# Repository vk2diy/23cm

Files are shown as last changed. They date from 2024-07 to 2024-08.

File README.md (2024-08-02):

# 23cm NBFM transceiver

An open source 23cm narrow band FM transceiver.

[KiCad](https://www.kicad.org/) format, optimized for building with [LCSC](https://www.lcsc.com/) and [JLCPCB](https://www.jlcpcb.com/).

Status: Schematic under active redefinition, BOM largely verified, firmware converted to platformio and compiling, some required symbols drawn, schematic as yet incomplete and revised layout not yet begun. Translated original article. Some mechanical design work and supply chain research completed. Getting bogged down in theory but learning a lot. Modeled some subsystems.

## Background

Prompted by a presentation by Richard (VK2VD) at Amateur Radio NSW on the 28th of July, 2024, this repository attempts to provide a design including all KiCad source files representing a derivative of the design by Bas de Jong (PE1JPD) with later firmware updates by Werner Mauser (JN48OL).

Various changes have been made to the design, outlined below.

## Original design details

Bas de Jong (PE1JPD)'s [original project page](http://www.pe1jpd.nl/index.php/23cm_nbfm/) describes the overall design, made in 2015, notably including this 2016 revised schematic.

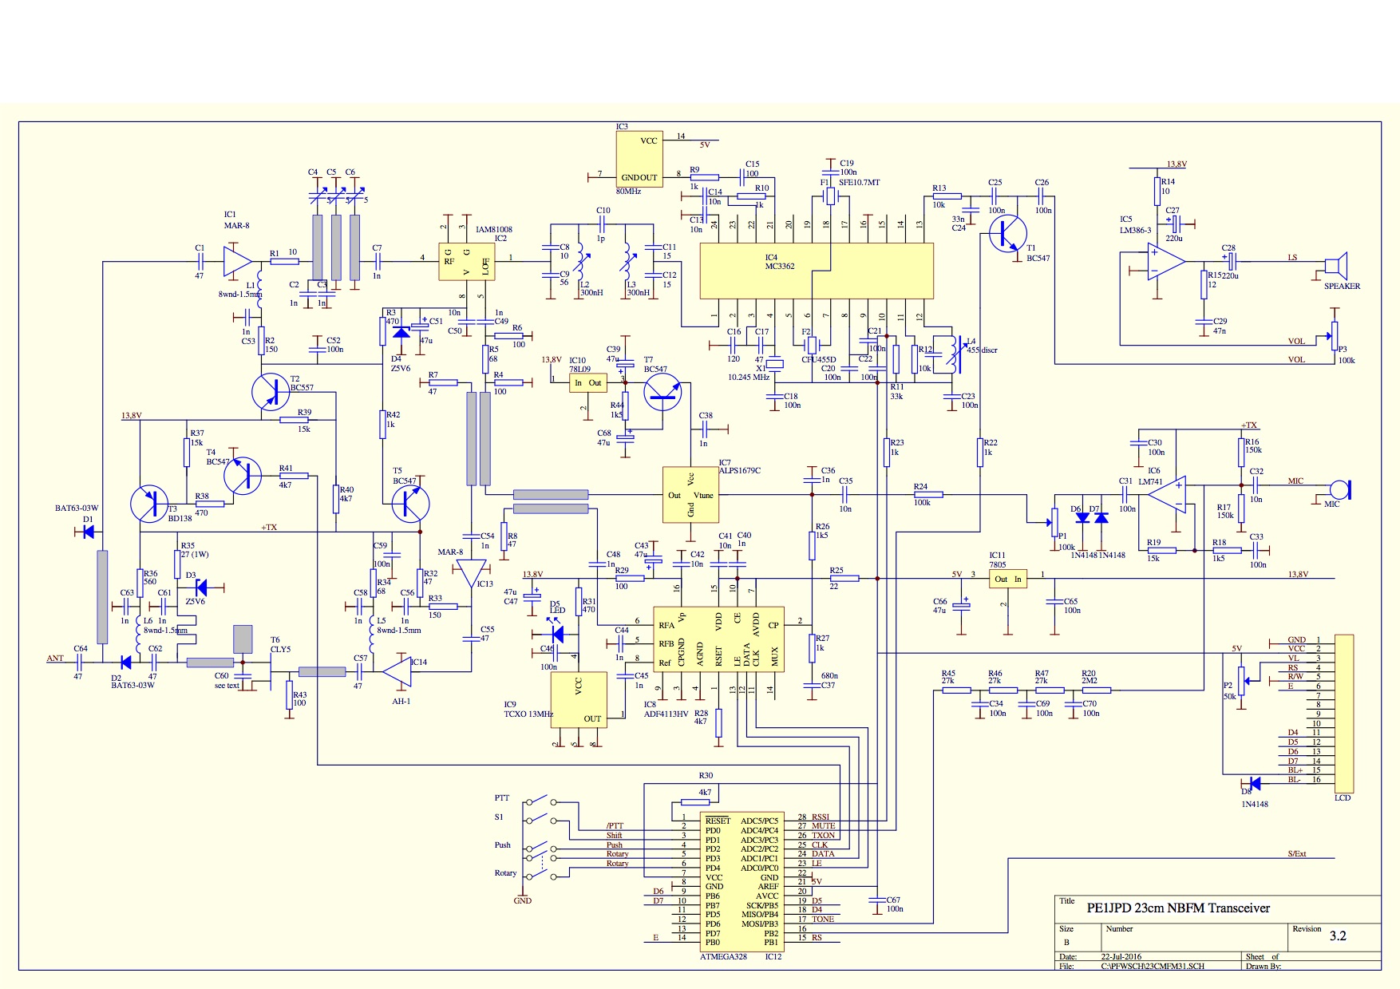
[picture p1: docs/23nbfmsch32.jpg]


Werner Mauser (JN48OL)'s [forked repository](https://github.com/wemaus/23cm-NBFM-Trx) provides firmware improvements, notably including a further revised schematic redrawn in KiCad 3.0.

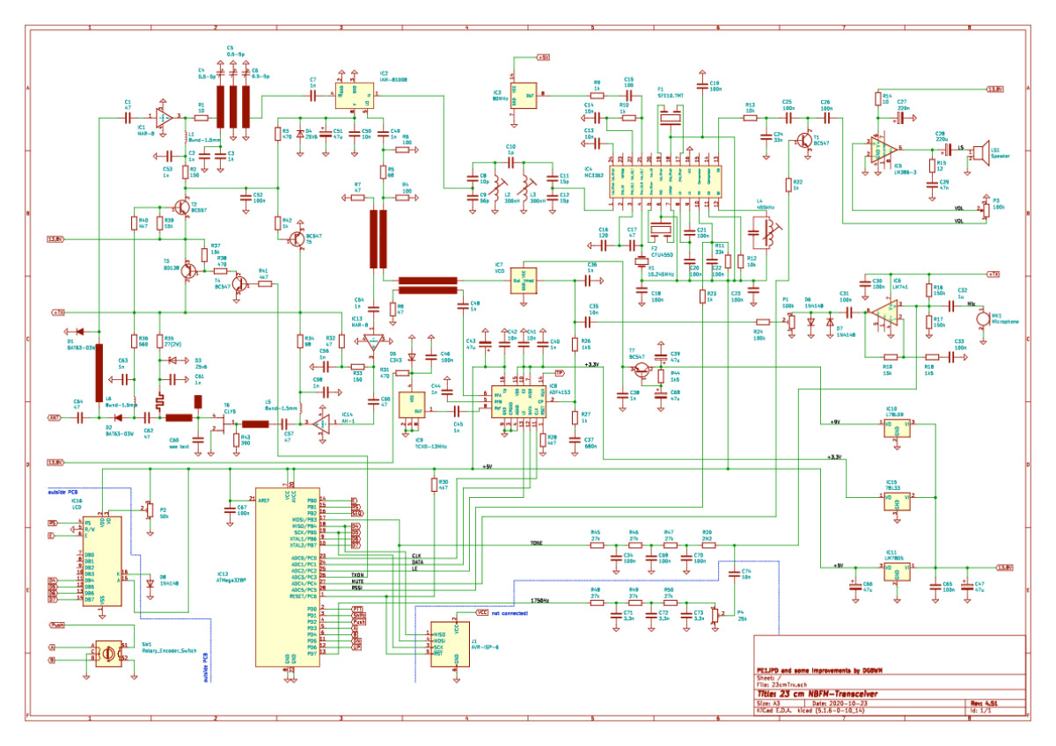
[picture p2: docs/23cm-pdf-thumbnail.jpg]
 

## Changes from prior versions

 * __Amplifier__: Maintained 2 x MAR-8 series amplifiers per original design, noting alternatives generally present worse noise performance, lower gain, and are footprint incompatible.
 * __Buses__: The "SPI compatible" bus on the ADF4153 was moved to the standard ports. The I2C bus was added to support the new display module and other expansion.
 * __Components__: Near complete reselection with a focus on SMT components available in 2024. General preference to over-specify components where economically insignificant to increase tolerance and longevity.
 * __Display__: Migrate the LCD to an I2C interface. Nominally opens up I2C for other peripherals and features. Much neater in terms of simplifying the schematic. Allows more flexibility in mechanical design/interface mounting. Necessitates re-allocating `MUTE` and `RSSI` to alternate pins, plus software changes. Necessitates off-board module and cable. Programmable backlight with MCU control, and one less knob. User retains option for manual adjustment using module-supplied jumper and internal potentiometer.
 * __Interface__: Try to migrate potentiometers to MCU-control where feasible, eg. CTCSS/1750MHz tuner, LCD backlight control.
 * __Filters__: [Explicitly modeling](docs/filter-models/) each filter network encountered. Apparently modern ceramic filters have superior properties in terms of bandwidth and attenuation compared to the dark depths of the 1990s from which the previous designs components were sourced.
 * __Firmware__: Now compiles with [platformio](https://piolabs.com/).
 * __MCU__: Use an MCU module (Arduino Nano v3) instead of a bare chip in order to reduce cost, increase convenience, support USB programming, and focus the schematic on the application.
 * __Oscillators__: Investigating the option/benefit/limitations of upgrading the reference temperature controlled crystal oscillator (TCXO) to a higher frequency and/or gold-plated version. Frequencies available include 14.4MHz, 20MHz, 28.8MHz, 30MHz, 50MHz, 100MHz, 200MHz. Nominally this will bring benefits in selectivity but also challenges. Availability seems a non-issue, cost differences are nominal.
 * __Power supply__: Drop 13.8V DC 'charged lead acid battery level' input to support a modern supply voltage (24V) and include a regulator with high current support.
 * __Schematic__: Completely redrawn to emphasize legibility through reducing cognitive load with block-based / modular schematic. Use named labels instead of single page all-in-one view with crossed nets. Hopefully still works!
 * __VCO__: Neither of the VCOs mentioned seem to be obtainable. A shortlist of potential replacements has been gathered. No doubt voltage levels on both the supply and tuning sides will need adjustment in order to integrate.
   * M1200 (+0-5V = 1150-1350MHz) - 6RMB @ [Manufacturer](https://www.fresend.com/productinfo/647892.html)
   * RFINT INNOTION YSGM 111308 (+0.5-4.5V = 1100-1350MHz, nominal 1050-1400MHz support) - $1.14 @ [AliExpress](https://www.aliexpress.com/item/1005005589982171.html)
   * FDK IR013 (1200-1400MHz) - $1.08 @ [AliExpress](https://www.aliexpress.com/item/1005007461973192.html)
   * UCVE1-W05A (marked "A041"; 1200-1670MHz) - $0.89 @ [AliExpress](https://www.aliexpress.com/item/1005005589963281.html)
   * MURATA MQW540A1G40R6 (1200-1600MHz) - $1.73 @ [AliExpress](https://www.aliexpress.com/item/1005007376224853.html)
   * MARUWA MVE-1377 (marked "E1377"; 1200-1400MHz) - $1.73 @ [AliExpress](https://www.aliexpress.com/item/1005007372058424.html)
   * ENFVH1D2SA4 (marked "12 VHA4"; 1200-1400MHz) - $2.16 @ [AliExpress](https://www.aliexpress.com/item/1005007376529487.html)

## Contents

 * __docs__: Design documentation. Some interesting stuff in here.
 * __firmware__: Currently unaltered firmware from Werner Mauser (JN48OL) converted to compile with platformio.
 * __23cm-trx-kicad__: KiCad project directory for the 23cm transceiver.

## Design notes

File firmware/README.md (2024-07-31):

# Firmware for 23cm NBFM transceiver

Currently unaltered firmware from [Werner Mause (JN48OL)](https://github.com/wemaus/23cm-NBFM-Trx).

The directory structure has been altered to match [platformio](https://piolabs.com/) standards.

The code is due to be modified to accomodate revised schematic.

In the mean time, the following works.

## Build the code

 * Normal build: `pio run`
 * Verbose build: `pio run -v`

## Lint the code

 * `pio check`

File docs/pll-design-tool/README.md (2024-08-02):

# PLL Design Tool

The tool recommended by the manufacture of the PLL synthesis chip is [ADIsimPLL](https://www.analog.com/en/lp/resources/adisimpll.html).

The version currently available for download was built on April 18, 2024.

## Download and install

The tool is designed for Windows but can be downloaded under Linux and run under [wine](https://www.winehq.org/).

The direct download script is as follows:

```
wget https://www.analog.com/media/en/engineering-tools/design-tools/adisimpll_v5_80_01_setup.zip && \
unzip adisimpll_v5_80_01_setup.zip && \
cd adisimpll_v5_80_01_setup && \
wine64-vanilla-9.0 ADIsimPLL_V5_80_01_setup.exe
```

Note that your `wine` instllation may required a slightly different binary name when executing the final command.

On any modern Linux, press `wine<tab><tab>` to see a list of contenders.

## Running the tool

Under Linux you can run the following command to start ADIsimPLL after installation.

```
wine64-vanilla-9.0 'c:\program files (x86)\applied radio labs\adisimpll ver 5.80\bin\simpll_ad.exe'
```

### Making things easier

There may be a better way to do this but I'm not a regular wine user.

Given this command line is a hassle to type, if you want to run this more than once you can create an alias like this:
```
alias adisimpll="wine64-vanilla-9.0 'c:\program files (x86)\applied radio labs\adisimpll ver 5.80\bin\simpll_ad.exe'"
```

Store than in your `~/.bashrc` (or other shell initialization file) in order to make it permanent.

You will now be able to run the tool by typing `adisimpll`.

## Notes

The software includes general rule-of-thumb characterisations of different filter designs which are presumably well founded.

## Tips

There is an interesting `tips.txt` file included with the software. A lot of it is marketing or irrelevant but some of the more interesting portions include:

 * You can measure the tuning data for a VCO (presumably a table of known input voltages vs. observed output oscillation frequencies), then store it in the system to model.
 * The ADF4116, ADF4117 and ADF4118 are pin compatible,  lower phase noise replacements for the LMX2306, LMX2316 and LMX2326 single devices respectively.   Drop-in replacements for the LMX dual devices are also available. The ADF4116, ADF4117 and ADF4118 devices use fixed prescalers and can operate up to 3.0GHz.   The ADF4110 through ADF4113 single PLL devices (and ADF4210 through ADF4213 dual PLL devices) allow control of prescaler division ratio and can operate up to 4.0GHz.
 * There is a reference doubler on-chip in all the ADF4000 series Fractional-N models. This allows the input reference signal to be doubled. This is useful for increasing the PFD comparison frequency. Making the PFD frequency higher improves the overall PLL system noise performance. Doubling the PFD frequency will usually result in an improvement in noise performance of 3dB.
 * For certain designs sourcing high performance clock devices is desirable in order to reduce jitter.
 * ADF4110 through ADF4113 single PLL devices (and ADF4210 through ADF4213 dual PLL devices) allow control of prescaler division ratio over the range 8/9, 16/17, 32/33 and 64/65. Minimizing the prescaler division ratio allows the phase detector to run at higher frequencies without missing channels, reducing phase noise and accelerating switching times. However, be sure to ensure that the highest output frequency from the prescaler does not exceed the Maximum Allowable Prescaler Output Frequency specified on the datasheet: ADI SimPLL automatically checks this.

## Screenshots

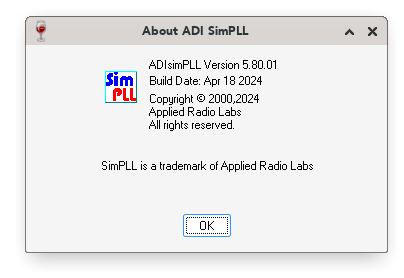
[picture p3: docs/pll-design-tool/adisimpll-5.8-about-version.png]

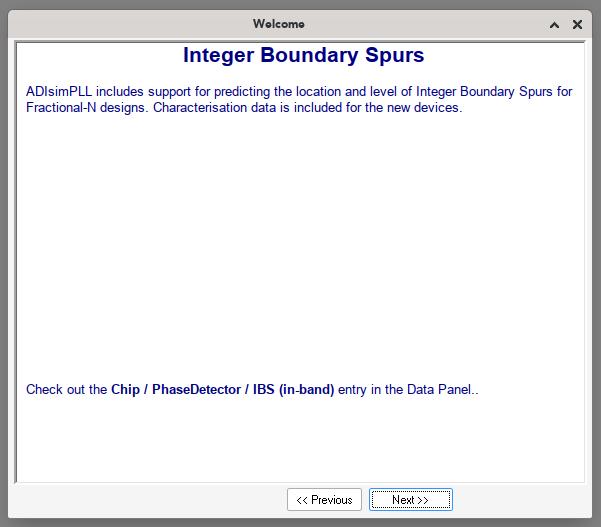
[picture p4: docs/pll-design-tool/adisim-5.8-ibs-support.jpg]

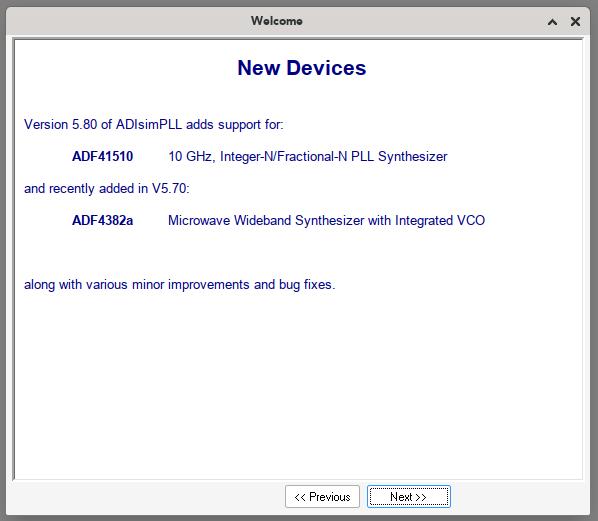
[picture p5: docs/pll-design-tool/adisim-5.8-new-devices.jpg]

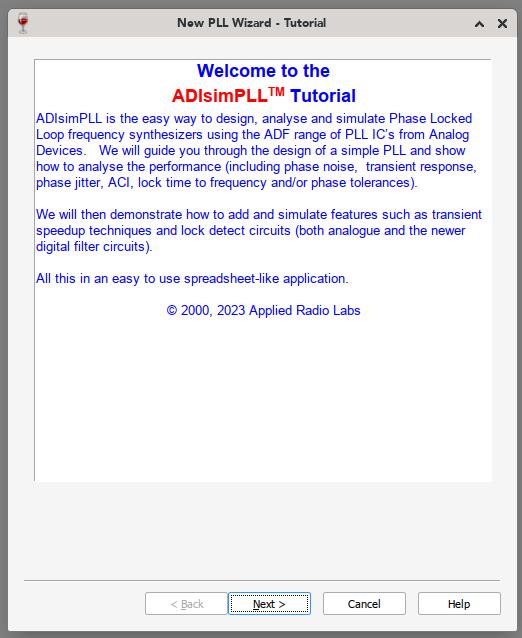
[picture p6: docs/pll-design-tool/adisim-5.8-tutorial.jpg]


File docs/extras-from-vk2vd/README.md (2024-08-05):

# Extra resources from VK2VD

VK2VD was kind enough to send me some further information.

First, he provided some English translations of stages 2 and 3 of [Wemaus' build site](http://www.mdtweb.de/index.php/projekte/nachrichtentechnik/nachrichtengeraete/23-cm-fm-transceiver/). I have not included those here in the repository because you can easily generate your own translations using [translate.google.com](https://translate.google.com) or similar services and being docx files with images they were relatively large.

Second, he provided a higher resolution version of his revised schematic which incorporates his suggested fixes to thermal issues observed with the previous schematic.

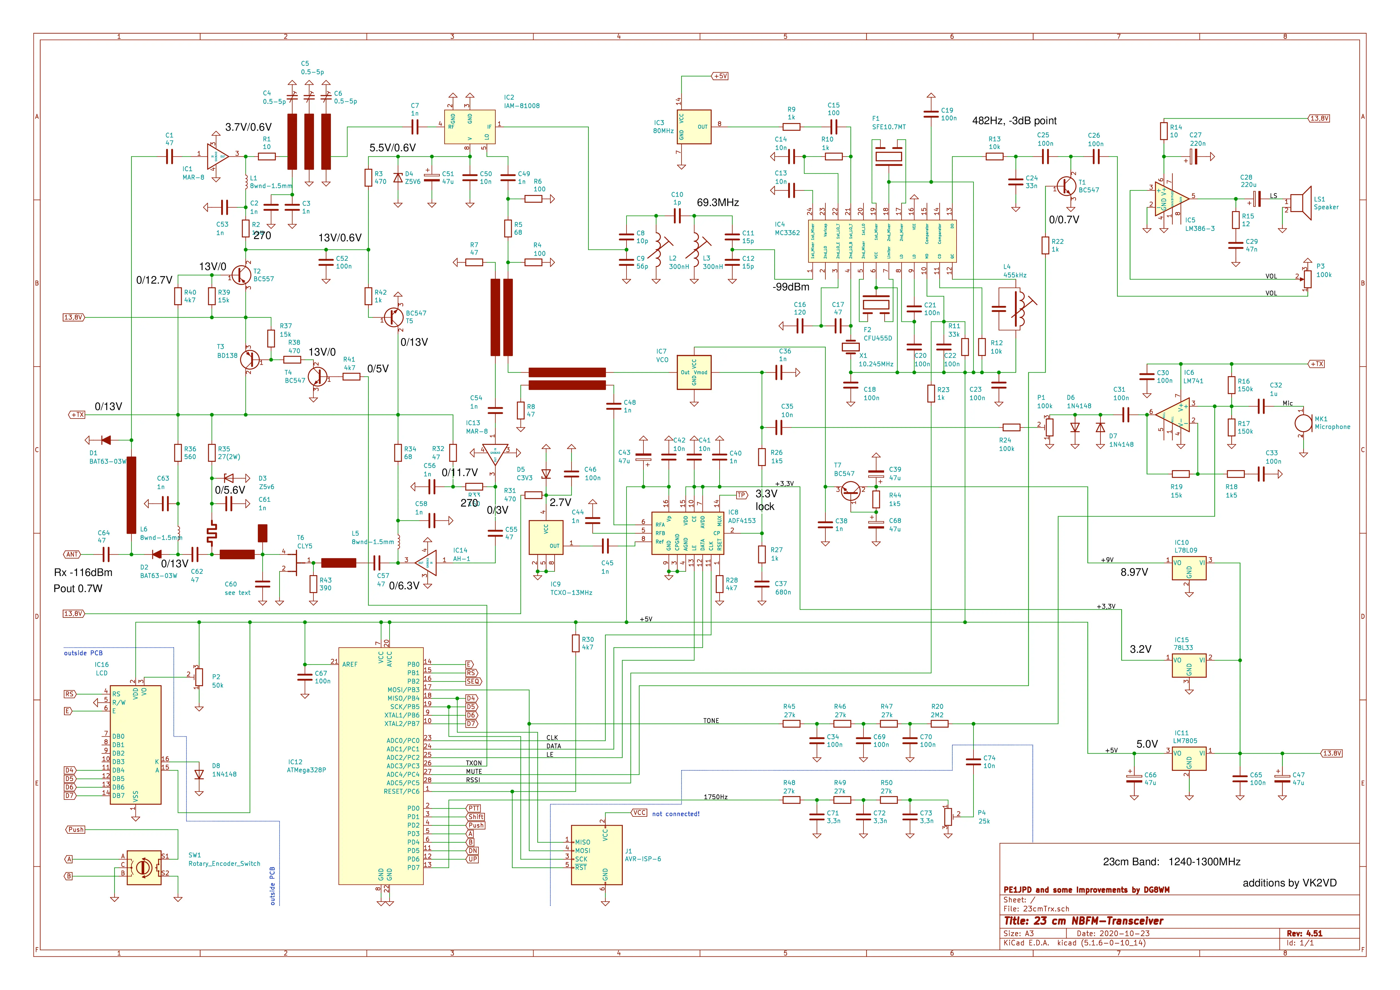
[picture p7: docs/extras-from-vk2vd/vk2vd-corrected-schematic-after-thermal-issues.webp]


Finally, he provided the following Sketch by DG8WM showing the PLL system.

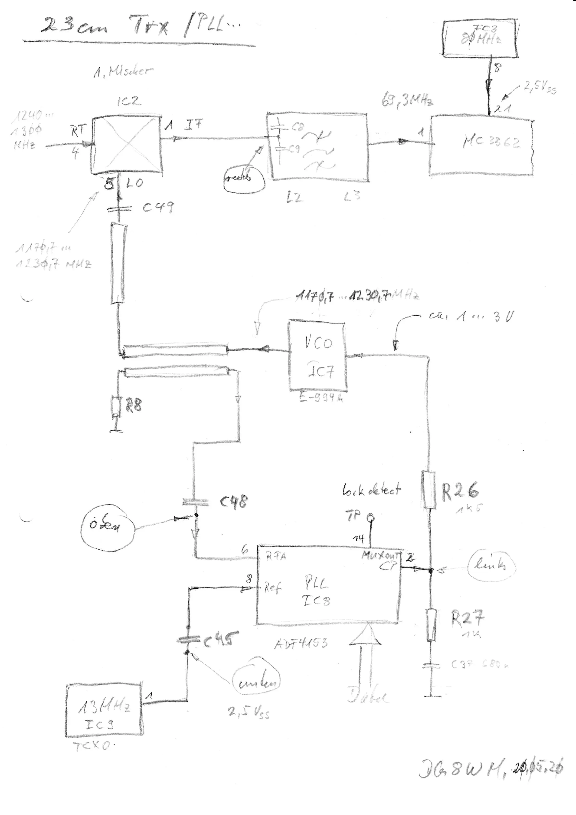
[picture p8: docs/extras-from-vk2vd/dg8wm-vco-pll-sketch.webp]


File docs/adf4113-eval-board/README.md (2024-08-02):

# ADF4113HV Eval Board

The evaluation board design is interesting. The PDF has further detail, but here is the base screenshot.

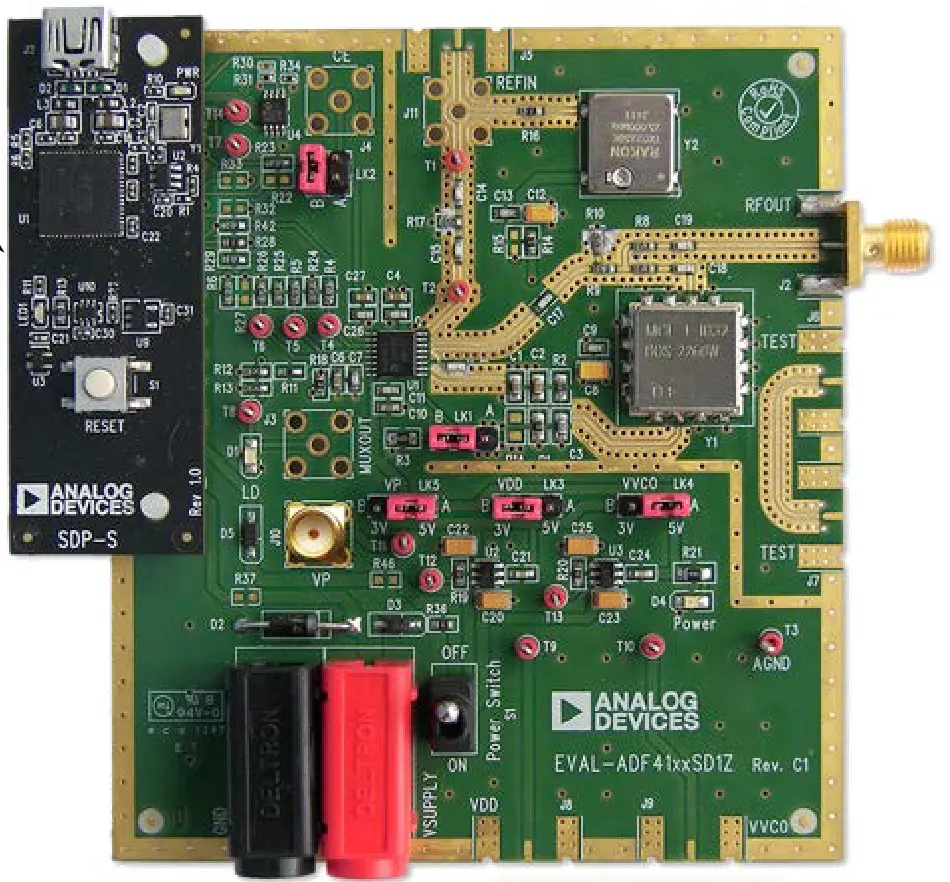
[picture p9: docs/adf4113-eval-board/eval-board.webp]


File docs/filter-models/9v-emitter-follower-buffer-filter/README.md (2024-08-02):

# 9V Emitter Follower Buffer

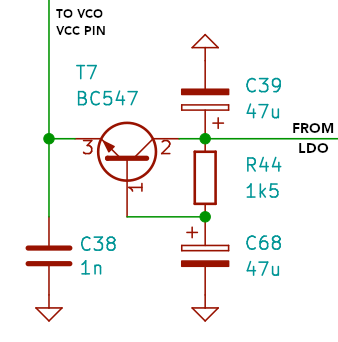
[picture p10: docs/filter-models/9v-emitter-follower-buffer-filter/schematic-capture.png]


This circuit provides stability and noise immunity for the VCO supply.

Here you can see the benefit of the circuit vs. a direct supply connection from the 9V LDO to the VCO VCC pin.

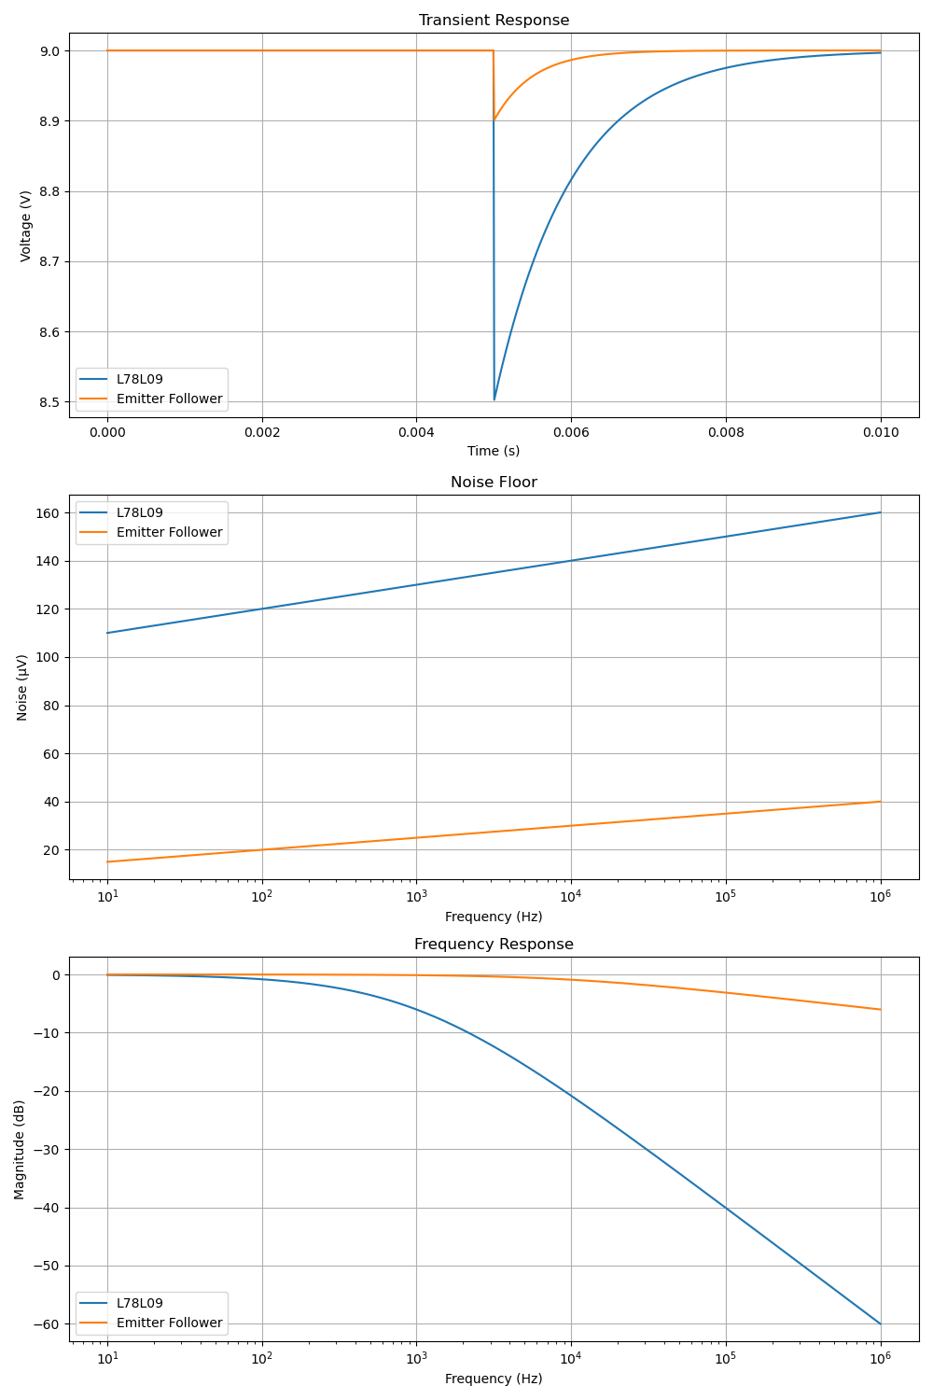
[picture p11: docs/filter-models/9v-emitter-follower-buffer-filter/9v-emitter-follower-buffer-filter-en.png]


Without a buffer filter, the following step response would be expected.

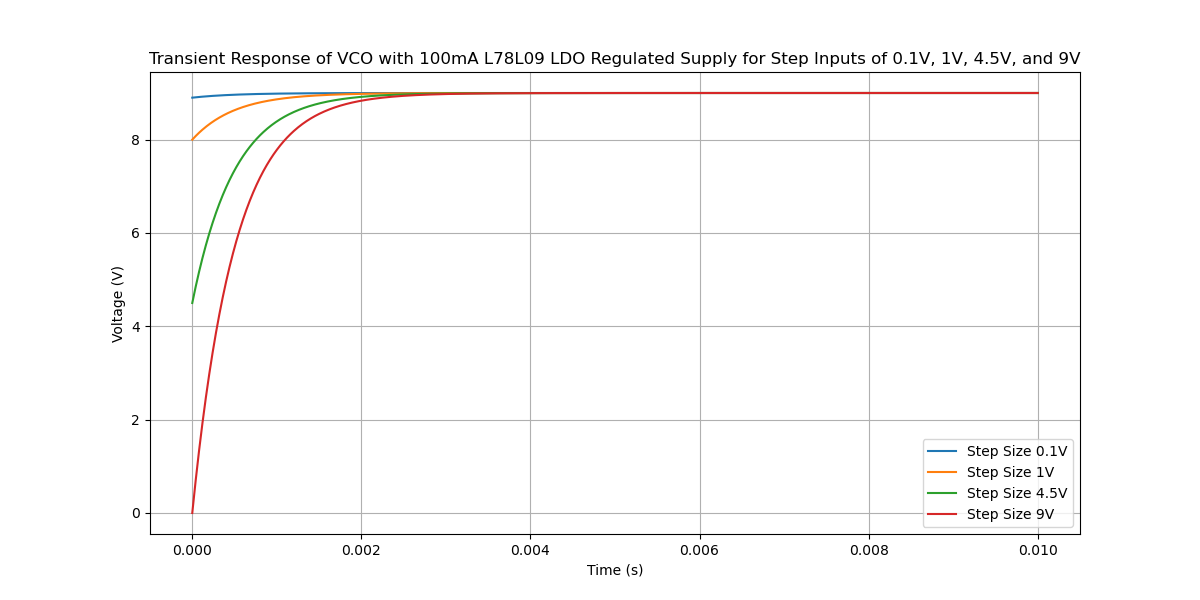
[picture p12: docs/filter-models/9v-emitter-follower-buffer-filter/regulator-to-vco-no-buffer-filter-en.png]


The impact of various buffer filter capacitor values are modeled here.

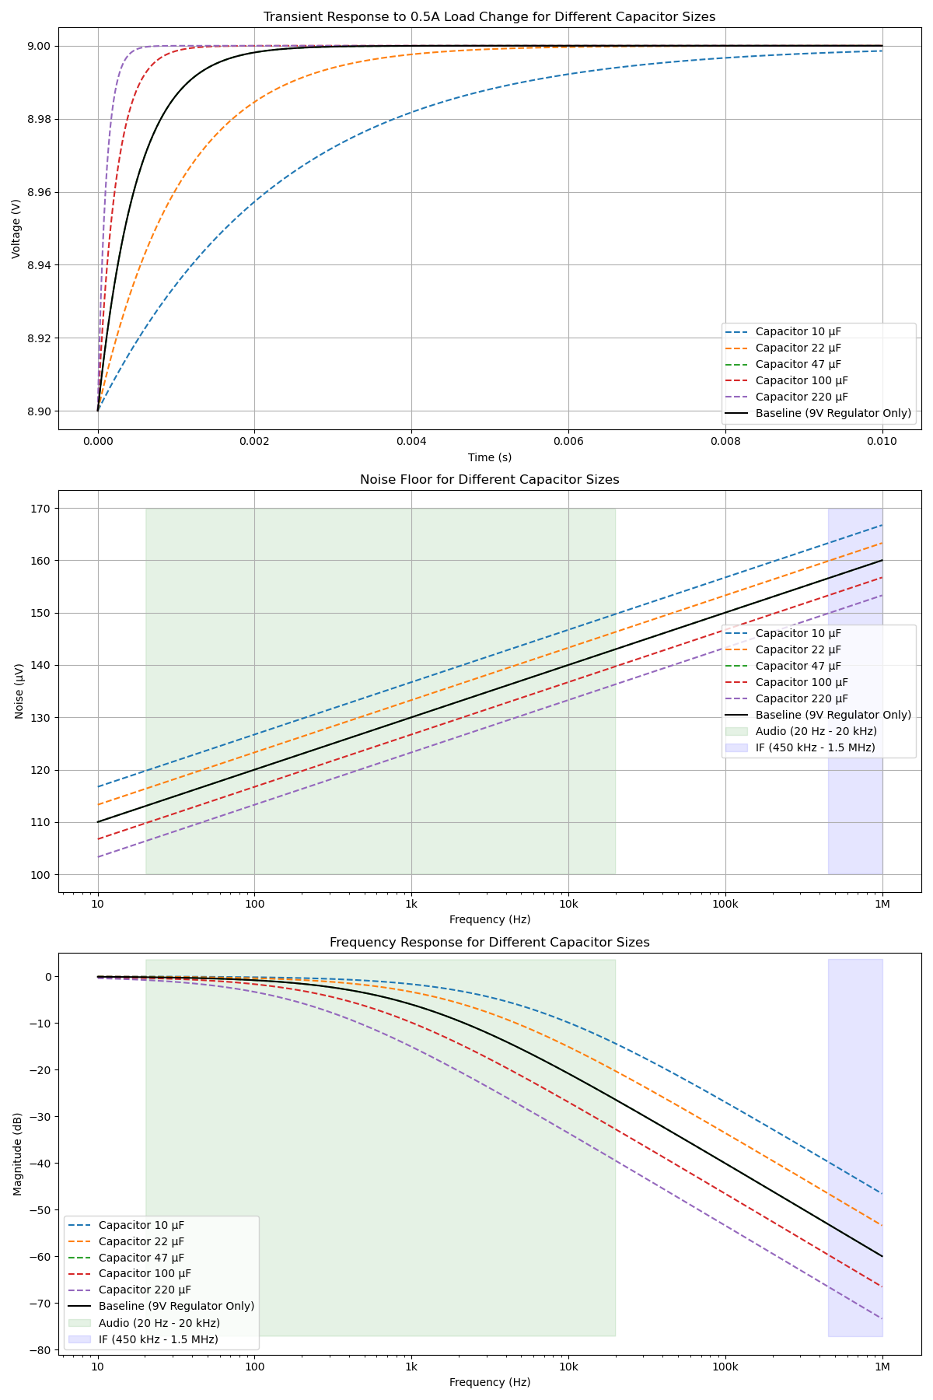
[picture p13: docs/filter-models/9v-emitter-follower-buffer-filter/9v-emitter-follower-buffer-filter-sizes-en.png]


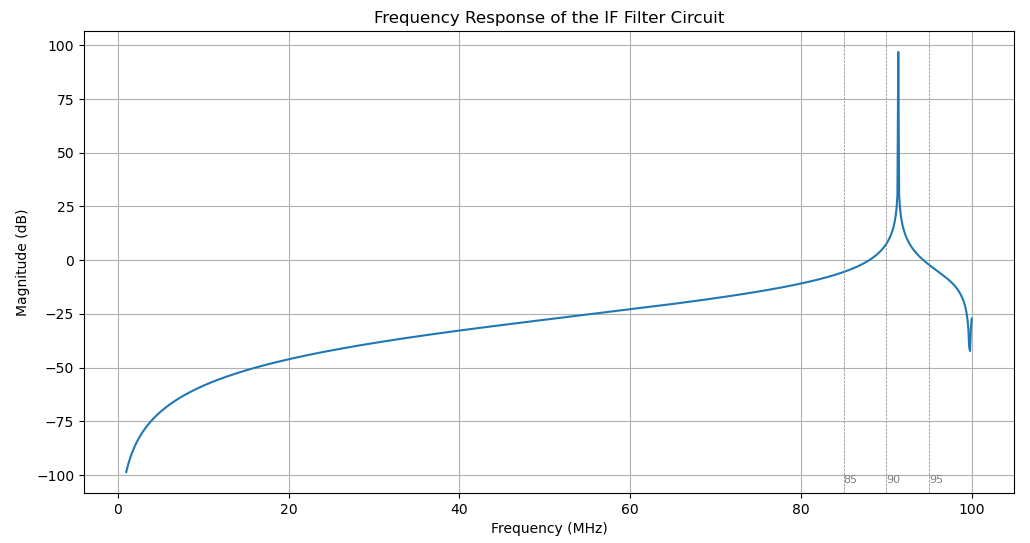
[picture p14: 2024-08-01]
docs/filter-models/if-filter/if-filter-vs-frequency.png

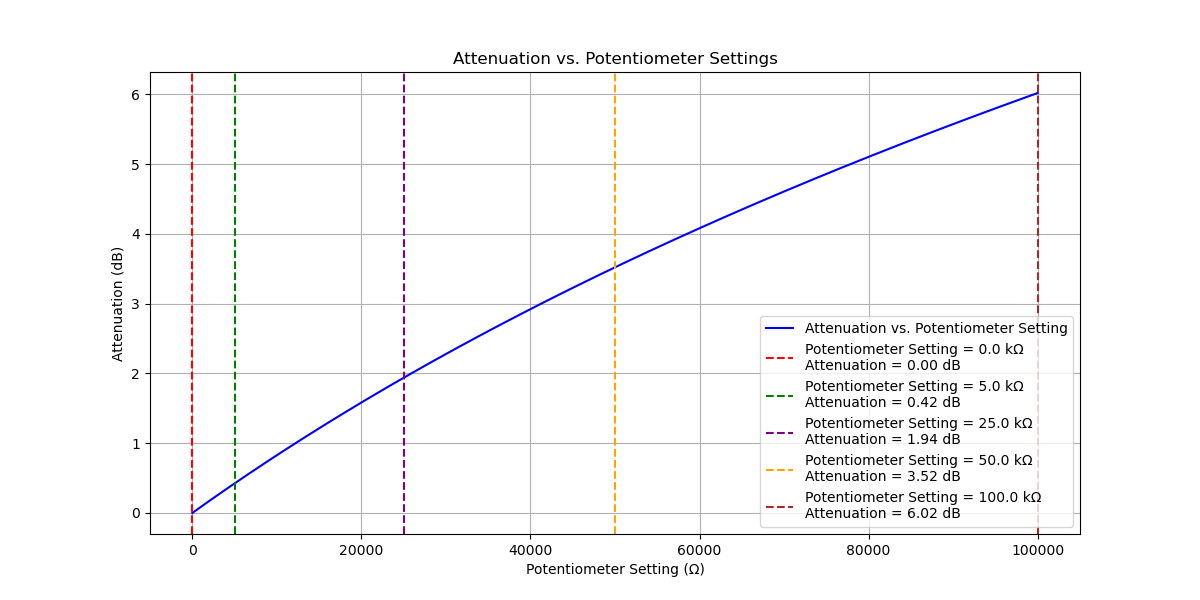
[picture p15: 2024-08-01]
docs/filter-models/clamp-and-attenuator/attenuation-vs-potentiometer.png

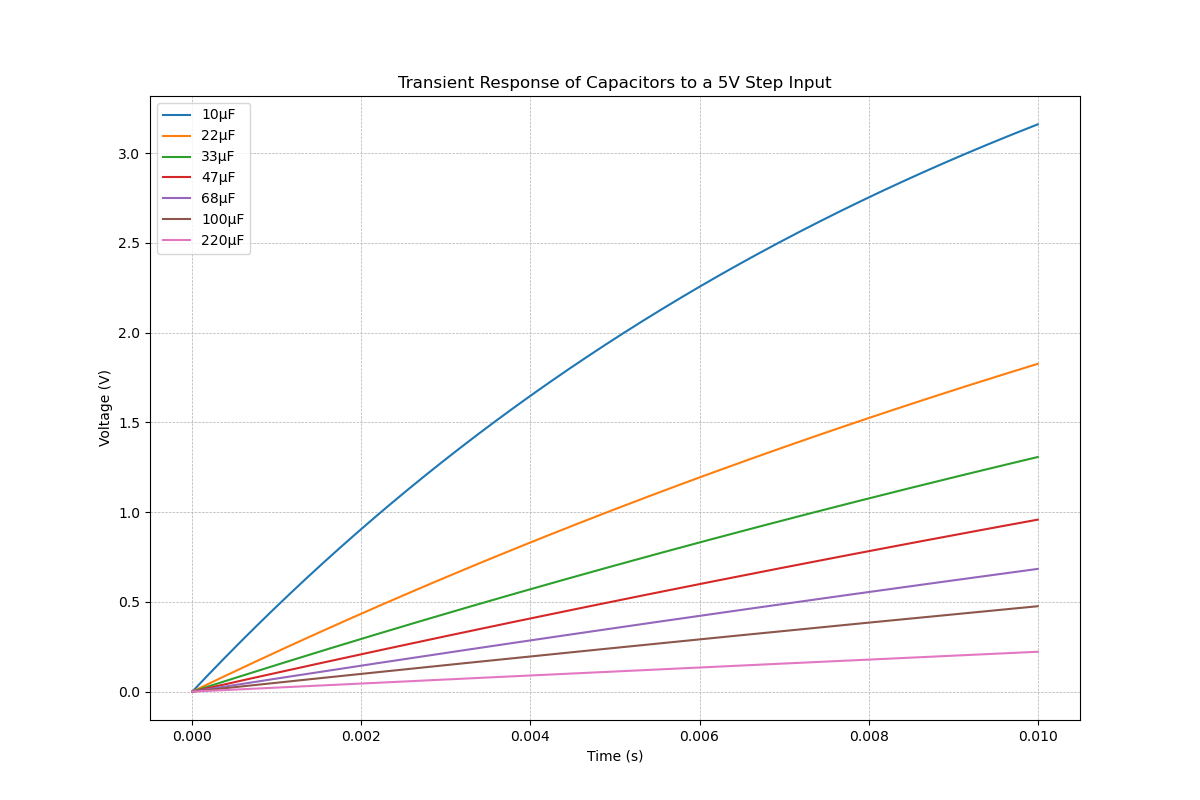
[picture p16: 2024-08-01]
docs/filter-models/pa-post-capacitance-vs-transient-response/pa-post-capacitance-vs-transient-response.png

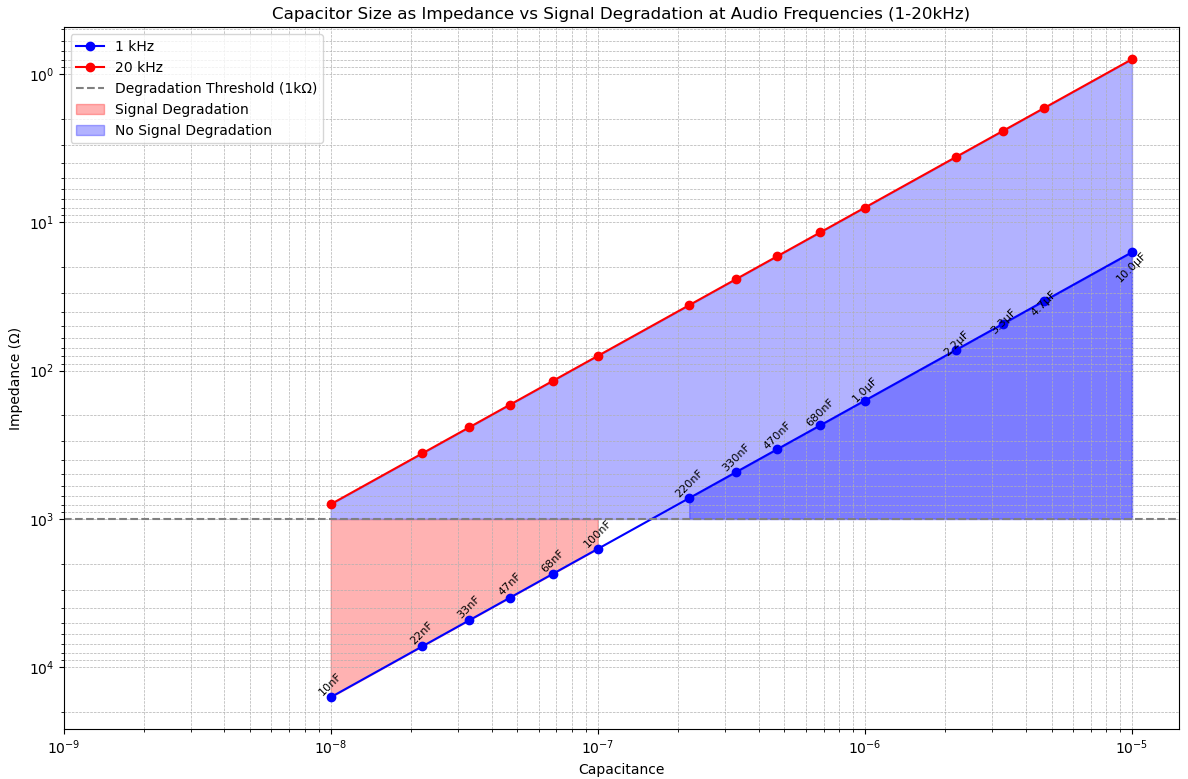
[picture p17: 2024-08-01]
docs/filter-models/pa-post-capacitance-as-impedance-vs-signal-degradation/pa-post-capacitance-as-impedance-vs-signal-degradation.png

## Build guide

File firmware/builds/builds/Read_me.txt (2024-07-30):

In this directory the most common builds can be found, ready to program as hex-file in an ATMega328p with factory fuse settings. 

Remarks:
========
- All versions are only compiled for 'Board2', 'TCXO 13 MHz' and 'PLL 4153'.
- Coax-Relay Port D7 (PD7) is changed to Port B2 (PB2) and PD7 is now used for 1750 Hz tone!

There are two different versions '2z' for LCD 2x16 characters and '4z' LCD 4x20 characters.

wm_23Trx_<software version>__<LCD type>.hex

For example:

wm_23Trx_4_4_4z.hex: Version 4.4, LCD 4x20.

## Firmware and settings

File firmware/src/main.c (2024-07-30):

/*
 * 23cm JPD transceiver
 * 
 * #	change												date		by
 * ---------------------------------------------------------------------------
 * 1.0	Initial version										01-01-15	pe1jpd
 * 1.5	Software squelch									26-05-15	pe1jpd
 * 2.0	PORTC change										01-07-15	pe1jpd
 * 2.1	PORTC bug solved									19-08-15	pe1jpd
 * 2.2	fref saved/restored from eeprom						02-10-15	pe1jpd
 * 3.1	New update, incl memories and scan					01-06-16	pe1jpd
 * 3.2	For AO-92, fref=5kHz, menu update					12-02-18	pe1jpd
 * 4.0	Support ADF4113 and ADF4153							12-04-18	pe1jpd
 * 4.1	Included sequencer koaxrelais PD7					12-04-18	pe1jpd
 * 4.2  LCD 4x20 ...										13-07-20	wm DG8WM
 * 4.2  Frequency Adjust +-999 KHz							14-07-20	wm
 * 4.2  Frequency Adjust +-200 KHz							16-07-20	wm
 * 4.2	Display Squelch, Shift, Step						16-07-20	wm
 * 4.2	max. Step 1000 KHz									16-07-20	wm
 * 4.2  New Encoder Handling								18-07-20	wm
 * 4.2	Display RSSI value in dBm							19-07-20	wm
 * 4.2	"V"FO Problem cleared								20-07-20	wm
 * 4.2	Display reverse	mode								20-07-20	wm
 * 4.2	Added "Hz" to CTCSS									21-07-20	wm
 * 4.2	2-line LCD improved									28-07-20	wm
 * 4.2	RSSI Display improved								28-07-20	wm
 * 4.2	Update Parameters in Memory Mode					30-07-20	wm
 * 4.2	Write only to eeprom, if value has changed			30-07-20	wm
 * 4.3	Write eeprom, correction (int)shift					12-08-20	wm
 * 4.3	Correction step down								12-08-20	wm
 * 4.3	Display in Memory Mode 'CTCSS', VFO Mode 'Step'		12-08-20	wm
 * 4.4  Change SEQ from PD7 to PB2							17-08-20	wm
 * 4.4	1750 Hz Tone PD7									17-08-20	wm
 * 4.4	Double click PTT for 1750 Hz tone					20-08-20	wm
 * 4.5	Start in VFO or MEMORY Mode							25-08-20	wm
 */


/*
 *
 *		'#define LCD_20x4' delete this for 2-line LCD in 23nbfm.h						wm
 *		'#define PB2_SEQ' for use PB2 and not PD7 for SEQ, PD7 is used for 1750 Hz		wm
 *		'#define TONE_1750' and '#define PB2_SEQ' 1750 Hz on PD7 						wm
 *
 */

#include <avr/io.h>
#include <stdio.h>
#include <avr/eeprom.h>
#include <avr/interrupt.h>
#include <avr/eeprom.h>												// wm
#include <avr/pgmspace.h>											// wm
#include "23nbfm.h"
#include <util/delay.h>

typedef unsigned char u08;

// variables
int squelchlevel;
int mode;
int selectedMemory;

int lastSelectedMemory;
int step, shift;

#ifdef ADF4153														// wm
	int frqadj;
#endif

long int freq, lastFreq;

int tx = FALSE;
int rv = FALSE;
int enc = 0;
char str[20];														// wm str[16];
int tick;

int tone;															// CTCSS-Tone
long toneCount;														// var for Timer1

#ifdef DECODER														// wm
	volatile int8_t enc_delta;										// Drehgeberbewegung zwischen zwei Auslesungen im Hauptprogramm
#endif

#ifdef DECODER														// wm
	// Dekodertabelle für wackeligen Rastpunkt
	// Quelle: https://www.mikrocontroller.net/articles/Drehgeber
	
	// viertel Auflösung											// wm
	const int8_t table[16] PROGMEM = {0,0,-1,0,0,0,0,1,0,0,0,0,0,0,0,0};

	// halbe Auflösung
	// const int8_t table[16] PROGMEM = {0,0,-1,0,0,0,0,1,1,0,0,0,0,-1,0,0};
		
	// Dekodertabelle für normale Drehgeber
	// volle Auflösung
	// const int8_t table[16] PROGMEM = {0,1,-1,0,-1,0,0,1,1,0,0,-1,0,-1,1,0};

	ISR( TIMER0_COMPA_vect )										// 1ms fuer manuelle Eingabe
	{
		static int8_t last=0;										// alten Wert speichern

		last = (last << 2)  & 0x0F;
		if (PHASE_A) last |=2;
		if (PHASE_B) last |=1;
		enc_delta += pgm_read_byte(&table[last]);
	}

	void encode_init( void )										// Timer 0 initialisieren
	{
		TIFR0 |= (1<<OCF0A);										// Clear Interrupt Request
		TIMSK0 |= 1<<OCIE0A;										// Enable Output Compare A Interrupt
		
//		OCR0A = (uint8_t)(XTAL / 8.0 * 1e-3 - 0.5);					// 1ms ==> XTAL/8 * 1e-3 - 0.5 = 124						<<<<<
		OCR0A = 125;												// 1ms Compare Time
		TCNT0 = 0;
		TCCR0A |= 1 << WGM01;										// CTC Mode 2
		TCCR0B |= 1 << CS01;										// Prescale XTAL / 8, Timer0 Start
	}
#else
	// Interrupt service routine INT1
	ISR(INT1_vect)
	{
		if (PIND & (1<<ROT))
 			enc++;
		else 
			enc--;

		_delay_ms(5);
	}
#endif


// Interrupt service routine Timer1
ISR(TIMER1_OVF_vect)				// CTCSS-Ton
{ 
	TCNT1 = 65535-toneCount;		// restart timer 1
	tick++;
	if (tx && tone>=600)
		tbi(PORTB, Beep);			// toggle Beep port	
} 

#ifdef TONE_1750													// wm
	// Interrupt service routine Timer2
	ISR(TIMER2_OVF_vect)											// 1750 Hz
	{
		if (tx && tone==599)
		{
			TCNT2 = 225;											// restart Timer 2, 1743 Hz
			tbi(PORTD, CT);											// toggle CT
		}
	}
#endif

void initInterrupts(void)
{
	#ifdef DECODER													// wm
		encode_init();
	#else
		EIMSK |= _BV(INT1);			// enable INT1
		EICRA |= _BV(ISC11);		// int1 on falling edge
	#endif

	// Setup Timer 1				// CTCSS
	TCCR1A = 0x00;					// Normal Mode 
	TCCR1B = 0x01;					// div/1 clock, F_CPU clock/1
	TIMSK1 |= (1 << TOIE1); 		// Timer1 overflow interrupt 

	#ifdef TONE_1750				// wm
		//Setup Timer 2				// 1750 Hz
		TCCR2A = 0X00;				// Normal Mode
		TCCR2B = 0x00;				// (F_CPU clock/8), stop Timer 2
		TIMSK2 |= (1 << TOIE2);		// Timer2 overflow interrupt 
	#endif

	// enable interrupts
	sei();
}


void adcInit(void)
{
	ADCSRA = (1<<ADPS0)|(1<<ADPS1)|(1<<ADPS2);  // prescaler /128
	#ifdef BOARD2
	DIDR0 = (1<<ADC5D); 			// disable digital input cannel 5
	ADMUX = (1<<REFS0) + 5;			// ADC channel 5, ARef = Vcc
	#endif
	#ifdef BOARD1
	DIDR0 = (1<<ADC0D); 			// disable digital input
	ADMUX = (1<<REFS0) + 1;			// ADC channel 1
	#endif
}


int getRotaryPush()
{
	int t, c = PIND;

	// rotary button pushed?
	if (!(c & (1<<PUSH))) {
		for (t=0; t<5; t++) {
			_delay_ms(100);
			// button released?
			if ((PIND & (1<<PUSH)))
			break;
		}
		if (t>3)
		return LONG;
		else
		return SHORT;
	}

	return FALSE;
}


#ifdef DECODER														//wm
	int handleRotary( void )         // Encoder auslesen
	{
		int8_t val = 0;

		// atomarer Variablenzugriff
		cli();
		
		if (enc_delta != 0) {
			if (enc_delta > 0) val = 1;
			else if (enc_delta < 0) val = -1; 
		 
			enc_delta = 0;
		}
		
		sei();
		return val;
	}
#else
	int handleRotary()
	{
		int count=0;

		if (enc != 0) {
			if (enc>0) count=1;
			else if (enc<0)count=-1;
			enc = 0;
		}
		return count;
	}
#endif


void hex2bcd(long int f)
{
	long int x = 10000000;
	int i;
	char d;

	for (i=0; i<8; i++) {
		d = 0;
		for (;;) {
			f -= x;
			if (f < 0) break;
			d++;
		}
		str[i] = d + 0x30;
		f += x;
		x = x/10;
	}
}


void displayFrequency(long int f)
{
	int i;
	char c;

	hex2bcd(f);

	lcdCursor(4,0);

	for (i=1; i<8; i++) {
		c = str[i];
		if (i==5) {
			lcdChar('.');
		}
		lcdChar(c);
	}
}


void displayParameter()												// wm
{
	lcdCursor(0,1);
	
	if (selectedMemory==MAXMEM)										// VFO Mode
	{
		sprintf(str, "Sq %2d Sh %3d St %4d", squelchlevel, shift, step);
	}
	else															// Memory Mode
	{
		if (tone<599)
		{
			sprintf(str, "Sq %2d Sh %3d To  off", squelchlevel, shift);
		}
		else if (tone==599)
		{
			sprintf(str, "Sq %2d Sh %3d To 1750", squelchlevel, shift);
		}
		else
		{
			sprintf(str, "Sq %2d Sh %3d To%3d.%1d", squelchlevel, shift, (int)(tone/10), (int)(tone%10));
		}
	}
	lcdStr(str);		
}


int TX_ok()												// wm
{
	// clear smeter
	int s = 0;
	
	#ifdef LCD_20x4										// wm Clear RSSI
		displayRSSI(s);
	#endif
	
	displaySmeter(s);									// Clear S-Meter
	// sequencer tx on
	switch_tx_on();
	// force update pll
	lastFreq = 0;
	tx = TRUE;
	
	return s;
}


int rxtx()
{
	int s;
	int t_1750;														// wm 

	// read ptt on PORTD
	int c = PIND;

	// listen reverse?
	if (rv) {
		if (c & (1<<REVERSE)) {
			lastFreq = 0;
			rv = FALSE;

			
			lcdCursor(3,0);
			lcdData(' ');
		}
	}
	else {
		if (!(c & (1<<REVERSE))) {
			lastFreq = 0;
			rv = TRUE;
			
			lcdCursor(3,0);
			lcdData(3);
		}
	}

	if (tx) {
		//keep smeter clear
		s = 0;
		// switch from tx to rx??									// PTT high switch Tx off
		if (c & (1<<PTT) ) 
		{
			#ifdef TONE_1750
				TCCR2B = 0x00;										// (F_CPU clock/8), stop Timer 2
				cbi(PORTD, CT);										// PB07 low
			#endif
			
			// sequencer tx off
			switch_tx_off();
			lastFreq = 0;
			tx = FALSE;
		}
	}
	else {
		s = readRSSI();
		
		#ifdef LCD_20x4												// wm
			displayRSSI(s);
		#endif
		
		displaySmeter(s);

		// switch from rx to tx?
		if (!(c & (1<<PTT)))								 			// PTT low switch Tx on 
		{
			#ifdef TONE_1750											// wm
				if (tone == 599)										// 1750 Hz is selected
				{
					tick = 0;											// reset counter, 1 tick  ~ 8 ms
					t_1750 = 0;
					
					do
					{
						_delay_ms(1);									// must be here
						if (PIND & (1<<PTT))							// PTT high
						{
							while ((tick < 20) && (PIND & (1<<PTT)));	// wait for PTT low or time out
						
							if (!(PIND & (1<<PTT)))
							{
								// switch on 1750 Hz
								TCCR2B = (1 << CS21);					// start Timer 2, F_CPU/8
								t_1750 = 1;								// PTT low --> 1750 Hz Tone
							}
							else
								t_1750 = -1;							// time out PTT high --> break
						}
						
						if (t_1750 != 0)
							break;
					}
					while ((tick < 20) && !(tx));
				
					if (t_1750 > -1)
						s = TX_ok();									// time out PTT low --> without 1750 Hz Tone
				}
				else			
					s = TX_ok();										// 1750 Hz not selected PTT low
			#else	
				s = TX_ok();
			#endif
		}
	}

	// calc value for ISR
	toneCount = 5*F_CPU/tone;										// CTCSS 

	// freq change or update needed?
	if (freq != lastFreq) {
		long int f = freq;
		if (tx) {
			f += (long int) shift*1000;
			setFrequency(f);
		}
		else {
			if (rv) f += (long int)shift*1000;
			setFrequency(f - IF);
		}
		
		displayFrequency(f);
		lastFreq = freq;
		
		#ifdef LCD_20x4												// wm
			displayParameter();
			lcdCursor(18,0);
			
			if (tx)
				lcdStr("Tx");
			else
				lcdStr("Rx");
		#else
			lcdCursor(15,0);
			if (tx)
				lcdChar('T');
			else
				lcdChar('R');
		#endif
	}

	return s;
}


void switch_tx_on()
{
	// mute receiver
	sbi(PORTC, MUTE);

	// switch coax relais to tx
	#ifdef PB2_SEQ													// wm
		sbi(PORTB, SEQ);
	#else
		sbi(PORTD, SEQ);
	#endif
	
	//wait a bit
	_delay_ms(200);
	// switch on tx
	sbi(PORTC, TXON);
}


void switch_tx_off()
{
	// switch tx off
	cbi(PORTC, TXON);
	// wait a bit
	_delay_ms(200);

	// switch coax relay to rx
	#ifdef PB2_SEQ													// wm
		cbi(PORTB, SEQ);
	#else
		cbi(PORTD, SEQ);
	#endif
}


void Test1()														// wm, normaly not used
{
	tbi(PORTB, SEQ);
	_delay_ms(5);
	tbi(PORTB, SEQ);	
}	
	

#ifdef ADF4113
void initPLL()
{
    long int reg;

    cbi(PORTC, DATA);
    cbi(PORTC, CLK);
    cbi(PORTC, LE);

	// set function latch
	reg = 0x438086;
    setPLL(reg);
    
    // init R-counter
	reg = (2UL<<16) + ((F_REF/25)<<2);
    setPLL(reg);

	unsigned long f = 1170000;
	setFrequency(f);

	reg = 0x438082;
	setPLL(reg);
}


void setFrequency(unsigned long f)
{
	long int reg, N, A, B;
    
	N = f/25;				// counter N in pll
	B = N/16;				// split in A and B
	A = N%16;
    
	reg = ((B & 0x1fff)<<8) + ((A & 0x3f)<<2) + 1;
    setPLL(reg);				// set pll
}
#endif 


#ifdef ADF4153
void initPLL()
{
    unsigned long reg, cntr, R, N, M, F, P1, MUX;

    cbi(PORTC, DATA);
    cbi(PORTC, CLK);
    cbi(PORTC, LE);

	// zero noise&spur registers
	reg = 0x000+3;
	setPLL(reg);

	// set lowest noise
	reg = 0x3c4+3;
	setPLL(reg);

	// reset control reg
	cntr = 0x001046;	//(0x10)+(1<<6)+(1<<2)+2;
	setPLL(cntr);

	// load MUX, R,M
	P1 = 0;
	R = 5;			// Fpfd = 2.6MHz
	M = 2600;
	MUX = 1;		// lock detect
	reg = (MUX<<20)+(P1<<18)+(R<<14)+(M<<2)+1; //0x4168a1
	setPLL(reg);

	// load N,F for F=1170MHz
	N = 450;
	F = 0;
	reg = (N<<14)+(F<<2); //0x708000
	setPLL(reg);

	// enable counter
	cntr = 0x001042;
	setPLL(cntr);
}


void setFrequency(unsigned long f)
{
	long int reg, N, F;

	N = (f+frqadj)/2600;											// wm
	F = (f+frqadj)-2600*N;											// wm

    reg = (N<<14)+(F<<2);
    setPLL(reg);
}
#endif


void setPLL(unsigned long r)
{
    int i;
    
    for (i=0; i<24; i++) {
        if (r & 0x800000)
            sbi(PORTC, DATA);
        else
            cbi(PORTC, DATA);
		_delay_us(10);
        sbi(PORTC, CLK);
        _delay_us(10);
        cbi(PORTC, CLK);
        r <<= 1;
    }
	_delay_us(10);
    sbi(PORTC, LE);
    _delay_us(10);
    cbi(PORTC, LE);
}



//=============================================================================
int main()
{
	// PORTB output for LCD
	DDRB = 0xff;
	
	#ifdef PB2_SEQ													// wm
		PORTB = 0xfb;												// PB2 for SEQ output low
	#else
		PORTB = 0xff;
	#endif

	#ifdef BOARD2
	// PORTC PC0-4 output, PC5 input
	DDRC = 0x1f;
	PORTC = 0x00;
	sbi(PORTC, MUTE);
	#endif
	
	#ifdef BOARD1
	// PORTC PC0,2-5 output, PC1 input
	DDRC = 0x3d;
	PORTC = 0x00;
	sbi(PORTC, MUTE);
	#endif

	// PD0-PD6 input with pullup, PD7 output, low
	// wm, PD7 used for 1750 Hz tone --> '#define PB2_SEQ' and '#define TONE_1750' 
	DDRD = 0x80;
	PORTD = 0x7f;

	lcdInit();
	adcInit();

	readGlobalSettings();
	
	if ((mode != VFO) && (mode != MEMORY))							// wm
	{
		mode = VFO;
	}
	
	toneCount = 5*F_CPU/tone;										// CTCSS, tick

	initInterrupts();
	initPLL();

	#ifdef LCD_20x4													// wm
		sprintf(str, "PE1JPD 23cm-Trx v%s", version);	
		lcdCursor(0,0);
		lcdStr(str);
		
		lcdCursor(0,1);
		lcdStr("   and improved by");
		
		lcdCursor(0,2);
		lcdStr("        DG8WM");
	#else
		sprintf(str, "PE1JPD 23cm v%s", version);
		lcdCursor(0,0);
		lcdStr(str);

		lcdCursor(0,1);
		lcdStr("Improv. by DG8WM");
	#endif
	
	_delay_ms(3000);												// wm 1000

	#ifdef LCD_20x4
		lcdCursor(0,2);
		lcdStr("              ");
	#endif

	for (;;) {
		switch(mode) {
			case VFO:
			mode = Vfo();
			writeGlobalSettings();
			break;
			case MEMORY:
			mode = Memory();
			writeGlobalSettings();
			break;
			case SPECTRUM:
			mode = Spectrum();
			break;
			case MENU:
			mode = Menu(mode);
			break;
			case MEMORY_MENU:
			mode = MemoryMenu(mode);
			break;
			default:
			mode = VFO;
			break;
		}
	}
}

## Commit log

2024-07-30 Additional schematic
2024-07-30 Schematic beginnings
    [23cm-trx-kicad.kicad_pcb, 23cm-trx-kicad.kicad_sch]
2024-07-30 More schematic
    [23cm-trx-kicad.kicad_sch]
2024-07-31 Further schematic work
    [23cm-trx-kicad.kicad_sch]
2024-07-31 LCD to I2C
    [23cm-trx-kicad.kicad_sch]
2024-07-31 More schematic work; additional project symbol table
    [23cm-trx-kicad.kicad_sch]
2024-07-31 Label PLL portions
    [23cm-trx-kicad.kicad_sch]
2024-07-31 VCO notes
    [23cm-trx-kicad.kicad_sch]
2024-08-01 Many component definitions
    [23cm-trx-kicad.kicad_sch]
2024-08-01 MC3362 symbol
    [23cm-trx-kicad.kicad_sch]
2024-08-01 IF filter
    [23cm-trx-kicad.kicad_sch]
2024-08-01 Model of filters
2024-08-01 IF filter model
2024-08-01 More schematic work
    [23cm-trx-kicad.kicad_sch]
2024-08-01 FM audio high pass filter
2024-08-01 Capacitance vs transient response
2024-08-01 Capacitance as impedance vs signal degradataion
2024-08-02 Reference design / eval board
2024-08-03 MCU back on A3 page
    [23cm-trx-kicad.kicad_sch]
